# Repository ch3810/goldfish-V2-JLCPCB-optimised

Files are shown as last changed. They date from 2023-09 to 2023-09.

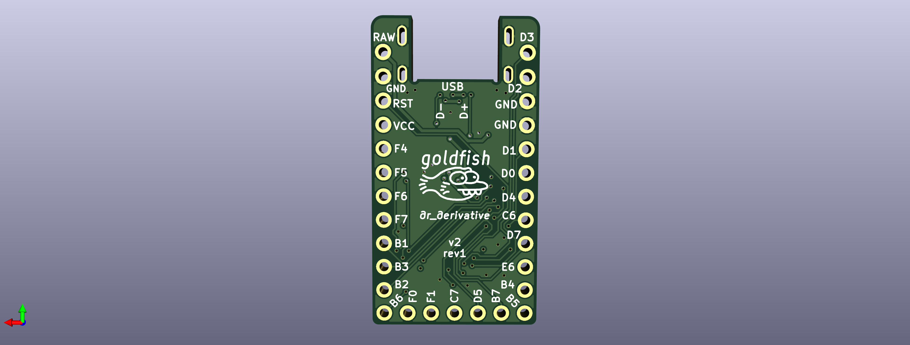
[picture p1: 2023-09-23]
docs/preview_4L_bot.png

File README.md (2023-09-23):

# Goldfish V2 - Orderable fully assembled via JLCPCB with 4L and 2L versions.

**Note: This branch contains the design for Goldfish v2. It has been modified from the original design (Credit: Lucas Jansen) to allow for compatible parts in the LCSC/JLCPCB library. 
Using the BOM, it will be possible to get a fully assembled design (outputs in cad/production). There are 2 project files which are based on specific kicad_sch and kicad_pcb files** 

**To open and work on the 2L version, open goldfish_2L.kicad_pro.**  
**To work on the 4L version, open goldfish.kicad_pro.**

**Only open the associated kicad_pcb file once the project is opened.** 

**The 4L version is highly recommended as the cost is almost the same and the signal integrity will be higher due to the full internal planes. The Goldfish v1 design files are available in the [v1 branch].**

---
Goldfish is a Pro Micro compatible microcontroller board designed for use in mechanical keyboards. It is based on the same Atmel ATMega32U4 chip and is programmable using the Arduino IDE or a keyboard specific firmware such as TMK or QMK. Of course it is perfectly usable for any other electronics projects too, not just keyboards.

preview

## Links

- [PCB Source Files]

- [Schematic]

- [BOM]

## Features

- Lower board profile with the mid-mounted USB-C connector
- Two internal pins make the USB data lines easily accessible
- USB-C is more durable, reversible and just plain cool
- 5 additional pins on the bottom edge of the board
- Pin-compatible with the original Pro Micro
- Sturdier through-hole USB connector
- On board ESD protection for USB lines

## Changes compared to Goldfish v1

- Addition of on board ESD protection and fuse
- All 0603 resistors and capacitors for (slightly) easier hand assembly
- Castellated edge connectors similar to the Elite-C
- Less obscure USB-C connector
  - Use of more commonly available components in 2022
  - Choice between multiple compatible connectors and suppliers
  - Uses USB 2.0-only connector for easier and cheaper assembly

connectors

## Disadvantages

- No onboard RX, TX LEDs
- No onboard voltage regulator (this makes no difference for keyboards; a regulator is only required when power supplies of over 5.5V are used)

## Vendors Selling Goldfish

#### Goldfish v1 rev. C

- [BeeKeeb]

#### Comet (modified design based on Goldfish v1; see related projects) 

- [Tokas' Kable Works]

**Note:** These products are sold by 3rd party vendors and are not 'officially' endorsed by me. I'm simply listing them here for convenience.

*(Also please let me know if anything is missing from this list)*

## Related Projects

#### [Alvaro] by Ariamelon

- A modified Goldfish v1 using 0603 components instead of 0402

#### [Comet] by Tokas

- A modified Goldfish v1 using a HRO TYPE-C-31-M-12 connector

#### [Whale] by Jia Geng Chang

- A modified Goldfish v1 using a Jing 918-418K2024S40000 connector

#### [Goldfish-clone-JLCPCB] by Jeremy J Starcher

- A modified Goldfish v1 designed to meet JLCPCB's assembly requirements

#### [Elite-C] from keeb.io

- An unrelated and closed source project with similar design goals

*(Please let me know if anything is missing form this list)*

## License

Released under the Creative Commons Attribution Share-Alike 4.0 License.  
https://creativecommons.org/licenses/by-sa/4.0/  

Original Arduino Mini Design by Team Arduino.  
Arduino Pro Mini Design by Spark Fun Electronics.  
Pro Micro Design by Spark Fun Electronics.  
Goldfish Design by Lucas Jansen.  

<!-- Links -->

[v1 branch]: https://github.com/staticintlucas/goldfish/tree/v1
[schematic]: docs/schematic.pdf
[BOM]: BOM.csv
[preview]: docs/preview.png
[connectors]: docs/connectors.png
[pcb source files]: cad

[beekeeb]: https://shop.beekeeb.com/product/goldfish-rev-c-open-source-pro-micro-replacement/
[tokas' kable works]: https://shop.tokas.co.uk/product/comet-usb-c-microcontroller/

[alvaro]: https://github.com/Ariamelon/Alvaro
[comet]: https://github.com/vattern/comet
[whale]: https://github.com/JiaGengChang/Whale
[elite-c]: https://keeb.io/products/elite-c-low-profile-version-usb-c-pro-micro-replacement-atmega32u4
[goldfish-clone-jlcpcb]: https://github.com/JeremyJStarcher/Goldfish-clone-JLCPCB

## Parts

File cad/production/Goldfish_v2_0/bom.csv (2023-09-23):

Designator | Footprint | Quantity | Value | LCSC Part #
C1, C10, C2, C3, C4, C5 | 0402 | 6 | 100nF | C363530
C6 | 0805 | 1 | 4.7uF | C384657
C7, C8 | 0402 | 2 | 15pF | C140684
C9 | 0603 | 1 | 1uF | C3015156
D1 | D_SOD-123F | 1 | D_Schottky | C908229
F1 | 1206 | 1 | 500mA | C492011
J1 | TYPE-610-1.6-T3 | 1 | USB_C_Receptacle_16P | C2972115
J3, J4 | Pins_x12 | 2 | Conn_01x12
J5 | Pins_x05 | 1 | Conn_01x05
R1, R2 | 0603 | 2 | 5k1 | C209245
R3, R6 | 0402 | 2 | 10k | C851039
R4, R5 | 0402 | 2 | 22R | C284431
U1 | QFN-44-1EP_7x7mm_P0.5mm_EP5.2x5.2mm | 1 | ATmega32U4-MU | C112161
U2 | SOT-666 | 1 | USBLC6-2P6 | C15999
X1 | Crystal_SMD_SeikoEpson_FA238-4Pin_3.2x2.5mm | 1 | 16MHz | C251610

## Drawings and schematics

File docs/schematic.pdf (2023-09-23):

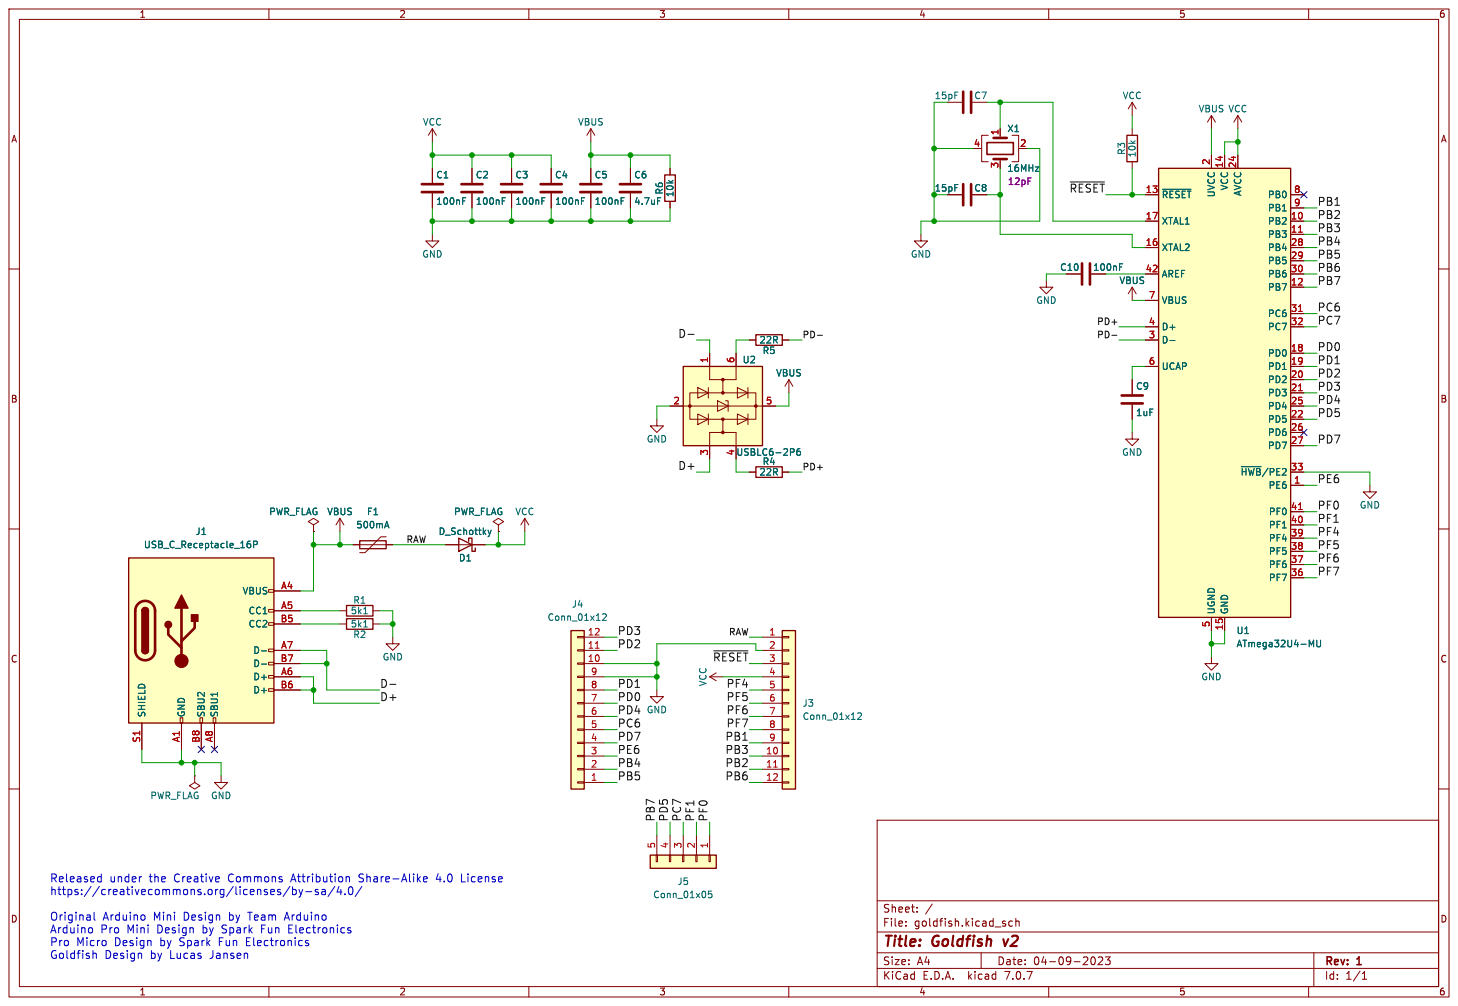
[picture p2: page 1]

2 PD2 20 PD3 21 PD5 22 AVCC 24 PD4 25 PD6 26 PD7 27 PB4 28 PB5 29 D- 3 PB6 30 PC6 31 PC7 32 ~{HWB}/PE233 PF7 36 PF6 37 PF5 38 PF4 39 D+ 4 PF1 40 PF0 41 AREF 42 UGND

https://creativecommons.org/licenses/by-sa/4.0/

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

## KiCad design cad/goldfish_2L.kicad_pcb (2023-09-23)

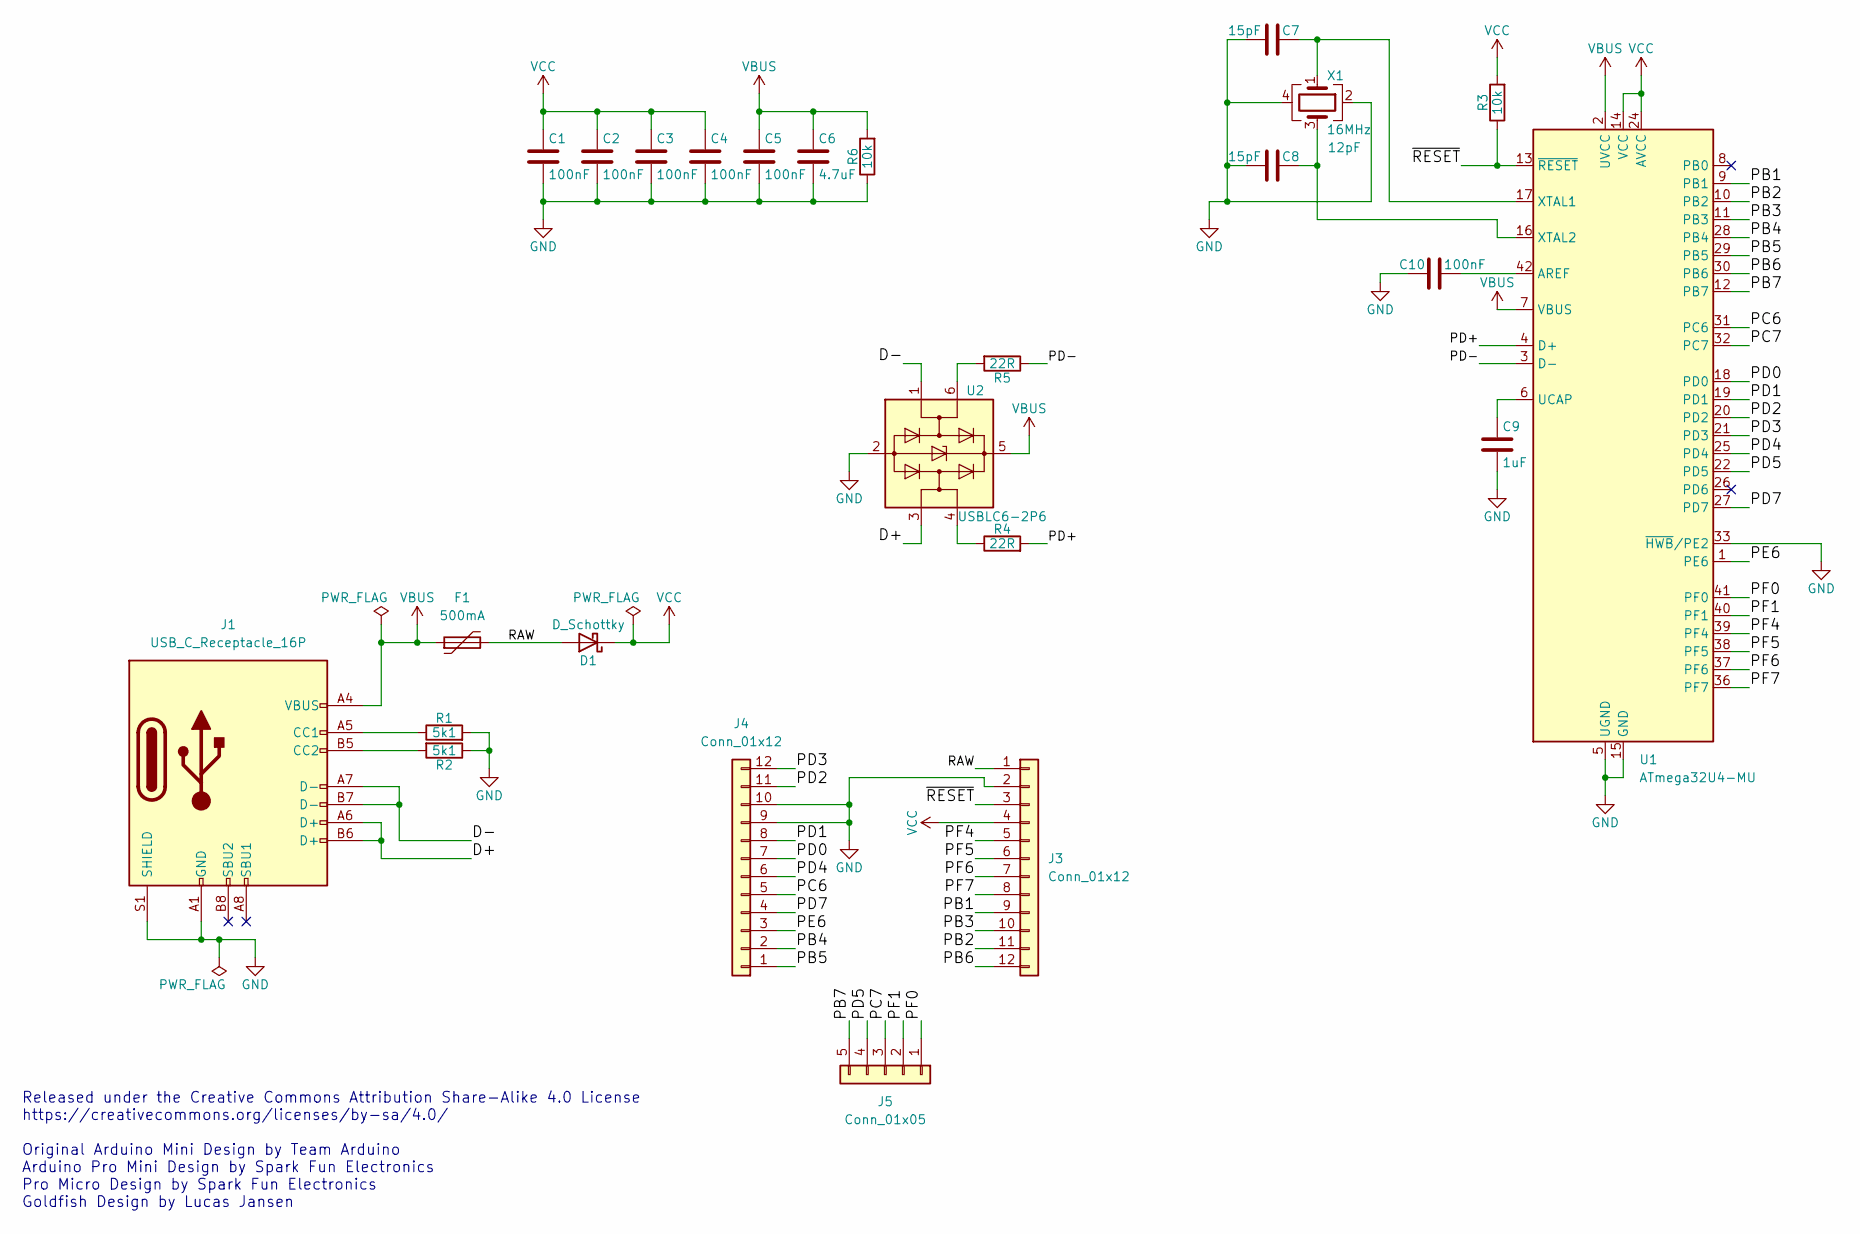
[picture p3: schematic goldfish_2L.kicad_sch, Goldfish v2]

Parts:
C1, C2, C3, C4, C5, C10: 100nF; C_0402_1005Metric; Tolerance 5%; MPN FN15X104J160PNG; JLCPCB C363530
C6: 4.7uF; C_0805_2012Metric; Tolerance 10%; MPN TT21X475K160CT; JLCPCB C384657
C7, C8: 15pF; C_0402_1005Metric; Tolerance 2%; MPN C0402C0G150G500NTB; JLCPCB C140684
C9: 1uF; C_0603_1608Metric; MPN CSA0603X5R105K160JT; JLCPCB C3015156
D1: D_Schottky; D_SOD-123F; MPN DSK24; JLCPCB C908229
F1: 500mA; Fuse_1206_3216Metric; MPN SMD1206P050TF/24; JLCPCB C492011
J1: USB_C_Receptacle_16P; TYPE-610-1.6-T3; MPN TYPE-610-1.6-T3; JLCPCB C2972115
J3, J4: Conn_01x12; Pins_x12
J5: Conn_01x05; Pins_x05
R1, R2: 5k1; R_0603_1608Metric; MPN RMS06JT512; JLCPCB C209245
R3, R6: 10k; R_0402_1005Metric; MPN AT0402BRD074K7L; JLCPCB C851039
R4, R5: 22R; R_0402_1005Metric; MPN ARG02FTC22R1; JLCPCB C284431
U1: ATmega32U4-MU; QFN-44-1EP_7x7mm_P0.5mm_EP5.2x5.2mm; MPN ATmega32U4-MU; JLCPCB C112161
U2: USBLC6-2P6; SOT-666; MPN USBLC6-2P6; JLCPCB C15999
X1: 16MHz; Crystal_SMD_SeikoEpson_FA238-4Pin_3.2x2.5mm; Tolerance 10ppm; MPN 7U16000E12UCG; JLCPCB C251610

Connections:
/D+: J1.A6 (D+), J1.B6 (D+), U2.3 (I/O2)
/D-: J1.A7 (D-), J1.B7 (D-), U2.1 (I/O1)
/PB1: J3.9, U1.9 (PB1)
/PB2: J3.11, U1.10 (PB2)
/PB3: J3.10, U1.11 (PB3)
/PB4: J4.2, U1.28 (PB4)
/PB5: J4.1, U1.29 (PB5)
/PB6: J3.12, U1.30 (PB6)
/PB7: J5.5, U1.12 (PB7)
/PC6: J4.5, U1.31 (PC6)
/PC7: J5.3, U1.32 (PC7)
/PD0: J4.7, U1.18 (PD0)
/PD1: J4.8, U1.19 (PD1)
/PD2: J4.11, U1.20 (PD2)
/PD3: J4.12, U1.21 (PD3)
/PD4: J4.6, U1.25 (PD4)
/PD5: J5.4, U1.22 (PD5)
/PD7: J4.4, U1.27 (PD7)
/PD+: R4.2, U1.4 (D+)
/PD-: R5.1, U1.3 (D-)
/PE6: J4.3, U1.1 (PE6)
/PF0: J5.1, U1.41 (PF0)
/PF1: J5.2, U1.40 (PF1)
/PF4: J3.5, U1.39 (PF4)
/PF5: J3.6, U1.38 (PF5)
/PF6: J3.7, U1.37 (PF6)
/PF7: J3.8, U1.36 (PF7)
/RAW: D1.2 (A), F1.2, J3.1
/~RESET: J3.3, R3.1, U1.13 (~RESET)
GND: C1.2, C2.2, C3.2, C4.2, C5.2, C6.2, C7.2, C8.2, C9.2, C10.2, J1.A1 (GND), J1.A12 (GND), J1.B1 (GND), J1.B12 (GND), J1.S1 (SHIELD), J3.2, J4.9, J4.10, R1.2, R2.1, R6.1, U1.5 (UGND), U1.15 (GND), U1.23 (GND), U1.33 (~HWB/PE2), U1.35 (GND), U1.43 (GND), U1.45 (GND), U2.2 (GND), X1.2, X1.4
unnamed: J1.A5 (CC1), R1.1
unnamed: J1.B5 (CC2), R2.2
unnamed: R4.1, U2.4 (I/O2)
unnamed: R5.2, U2.6 (I/O1)
unnamed: C10.1, U1.42 (AREF)
unnamed: C9.1, U1.6 (UCAP)
unnamed: C7.1, U1.17 (XTAL1), X1.1
unnamed: C8.1, U1.16 (XTAL2), X1.3
VBUS: C5.1, C6.1, F1.1, J1.A4 (VBUS), J1.A9 (VBUS), J1.B4 (VBUS), J1.B9 (VBUS), R6.2, U1.2 (UVCC), U1.7 (VBUS), U2.5 (VBUS)
VCC: C1.1, C2.1, C3.1, C4.1, D1.1 (K), J3.4, R3.2, U1.14 (VCC), U1.24 (AVCC), U1.34 (VCC), U1.44 (AVCC)

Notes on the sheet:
Released under the Creative Commons Attribution Share-Alike 4.0 License https://creativecommons.org/licenses/by-sa/4.0/ Original Arduino Mini Design by Team Arduino Arduino Pro Mini Design by Spark Fun Electronics Pro Micro Design by Spark Fun Electronics Goldfish Design by Lucas Jansen

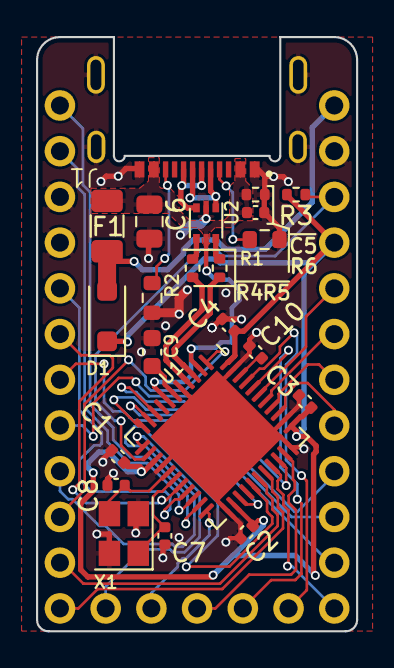
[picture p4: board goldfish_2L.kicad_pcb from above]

Board: 2 copper layers, 17.8 x 33.0 mm, 25 parts (0 on the bottom side), 40 nets.

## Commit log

2023-09-23 Initial release - contains a 4L version and a 2L version project based on the same schematic, all libraries combined into one
    [goldfish_2L.kicad_pcb]
2023-09-23 corrected front silkscreens and added schematic PDF files
    [goldfish.kicad_pcb, goldfish.kicad_sch, goldfish_2L.kicad_pcb]
2023-09-23 made a second kicad_sch file to simplify netlist process as it can be harder to manage otherwise. Also added production files for JLCPCB and gerbers inside cad/production folder
    [bom.csv, designators.csv, goldfish.kicad_pcb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]
